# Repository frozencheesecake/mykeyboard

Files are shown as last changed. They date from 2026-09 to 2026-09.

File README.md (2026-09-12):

## **A mechanical keyboard.**

I  decided to embark on a mission to make my own mechanical keyboard from scratch. This includes designing the PCB and the case for the keyboard myeslf. Since I have not made any PCB's before, this was be a completely new experience and fruitful experience for me :)

##### Details

> 83 keys (~75% keyboard)

> Non-hotswappable Akko V3 Creamy Purple Pro Switches

> Runs on a Raspberry Pi Pico due to its powerful chip and the number of IO pins (26 pins)

> Has a 16x6 matrix

> 1N4148 through-hole diodes to prevent ghosting (The matrix is a useful way of succinctly employing a limited number of IO pins for a large number of keys.)

[Bill of Materials](https://github.com/bamb-boo/keyboard/blob/main/cart/bom-keyboard_kicad.csv)-
| Component name | Details | Qty | Bought from | Cost (usd) |
|---|---|---|---|---|
| Case | PLA | 1 | JLCPCB | ~70 |
| Plate | Resin | 1 | JLCPCB | 6 |
| Switches | Click Inc HP Switch (Pack of 10) | 9 packs | https://stackskb.com/store/click-inc-hp-switch-pack-of-10-pre-order/ | 17 |
| Keycaps | Color PBT | 83 keycaps | https://meckeys.com/shop/accessories/keyboard-accessories/keycaps/colour-pbt-keycaps/ | about 11 |
| M2 nuts and bolts | 15 mm height | 8 | Local vendor | 1 |
| Microcontroller | Raspberry Pi Pico | 1 | https://quartzcomponents.com/products/raspberry-pi-pico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 | 3.5 |
| Stabilizers | 4 x 2u + 1 x 6u | 5 | https://www.genesispc.in/products/durock-plate-mount-stabilizers-6-25u-4x2u-black?variant=43129560924213 | 4 |
| Diodes | 1n4148 | 83 | https://www.ktron.in/product/diode-1n4148-th/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 | 0.6 |

Exclaimer- the bom.csv in the cart dir is for all products. the bom.csv in the pcb dir is the bom generated by kicad itself. attaching both for convinience sake ig?

Future scope-

> A keyboard using a touchscreen to for more efficiency

> Wireless version using Pi Pico W.

There are two main folders, 1 for the PCB and another for the CAD files for the case and the plate. 

I had a faulty laptop keyboard, and wanted to get a mechanical keyboard. I felt creating my own mechanical keyboard will not only fix my need, but will also be a good learning opportunity.

Photos-





Build instructions-

Solder the diodes to the designated holes in the pcb, with the diodes pointing dows.

Solder the switches to the holes beside the diodes.

Attach the keycaps to the switches.

Attach the pcb to the plate, ensuring the fit snugly.

Bolt the plate to the case.

Viola, you're done!

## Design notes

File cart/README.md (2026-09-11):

all components-

pcb-


case and plate- friend

[switches](https://stackskb.com/store/click-inc-hp-switch-pack-of-10-pre-order/)

[keycaps](https://meckeys.com/shop/accessories/keyboard-accessories/keycaps/colour-pbt-keycaps/). alternative if not available- [https://meckeys.com/shop/accessories/keyboard-accessories/keycaps/royal-kludge-blue-mix-keycaps/](https://meckeys.com/shop/accessories/keyboard-accessories/keycaps/royal-kludge-blue-mix-keycaps/)

[stabilizers](https://www.genesispc.in/products/durock-plate-mount-stabilizers-6-25u-4x2u-black?variant=43129560924213)

microcontroller- raspberry pi pico

[1n4148 diodes](https://www.ktron.in/product/diode-1n4148-th/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)

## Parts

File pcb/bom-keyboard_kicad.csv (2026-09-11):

Id | Designator | Footprint | Quantity | Designation | Supplier and ref
1 | SW83,SW71,SW4,SW54,SW41,SW18,SW38,SW44,SW82,SW46,SW9,SW15,SW81,SW58,SW43,SW6,SW22,SW60,SW37,SW52,SW36,SW50,SW33,SW2,SW35,SW20,SW56,SW7,SW62,SW31,SW14,SW26,SW66,SW10,SW1,SW39,SW80,SW70,SW8,SW53,SW73,SW5,SW27,SW42,SW68,SW51,SW3,SW57,SW25,SW23,SW79,SW29,SW17,SW13,SW24,SW12,SW28,SW65,SW21,SW69,SW63,SW67,SW34,SW16,SW19,SW55,SW48,SW40,SW64,SW49,SW11 | MX_PCB_1.00u | 71 | SW_Push
2 | SW75,SW74,SW77,SW76 | MX_PCB_1.25u | 4 | SW_Push
3 | SW45,SW32 | MX_PCB_1.50u | 2 | SW_Push
4 | SW59,SW61 | MX_PCB_2.25u | 2 | SW_Push
5 | SW30 | MX_PCB_2.00u | 1 | SW_Push
6 | SW78 | Stabilizer_Cherry_MX_6.25u | 1 | SW_Push
7 | SW47 | MX_PCB_1.75u | 1 | SW_Push
8 | SW72 | MX_PCB_2.75u | 1 | SW_Push
9 | D52,D35,D94,D61,D90,D29,D97,D47,D23,D51,D63,D43,D26,D22,D38,D105,D67,D30,D17,D15,D19,D10,D69,D34,D82,D33,D39,D50,D66,D45,D77,D79,D59,D53,D64,D80,D104,D37,D73,D78,D36,D92,D65,D13,D88,D24,D20,D32,D11,D60,D44,D72,D42,D14,D12,D41,D95,D49,D16,D86,D93,D54,D27,D58,D18,D74,D31,D96,D85,D81,D28,D84,D75,D21,D56,D91,D55,D25,D57,D62,D48,D76,D46 | D_DO-35_SOD27_P3.81mm_Vertical_KathodeUp | 83 | ~
10 | U1 | Raspberry_Pi_Pico | 1 | Raspberry_Pi_Pico

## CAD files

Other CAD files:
cad/complete_build/case (Assembly).step
cad/case/keyboard_case.step
cad/plate/keyboard_case.stl
cad/plate/keyboard_plate.step
cad/case/case.f3d
cad/case/keyboard_case.stl
cad/complete_build/case (Assembly).f3z
cad/complete_build/case (Assembly).stl
cad/plate/plate.f3d

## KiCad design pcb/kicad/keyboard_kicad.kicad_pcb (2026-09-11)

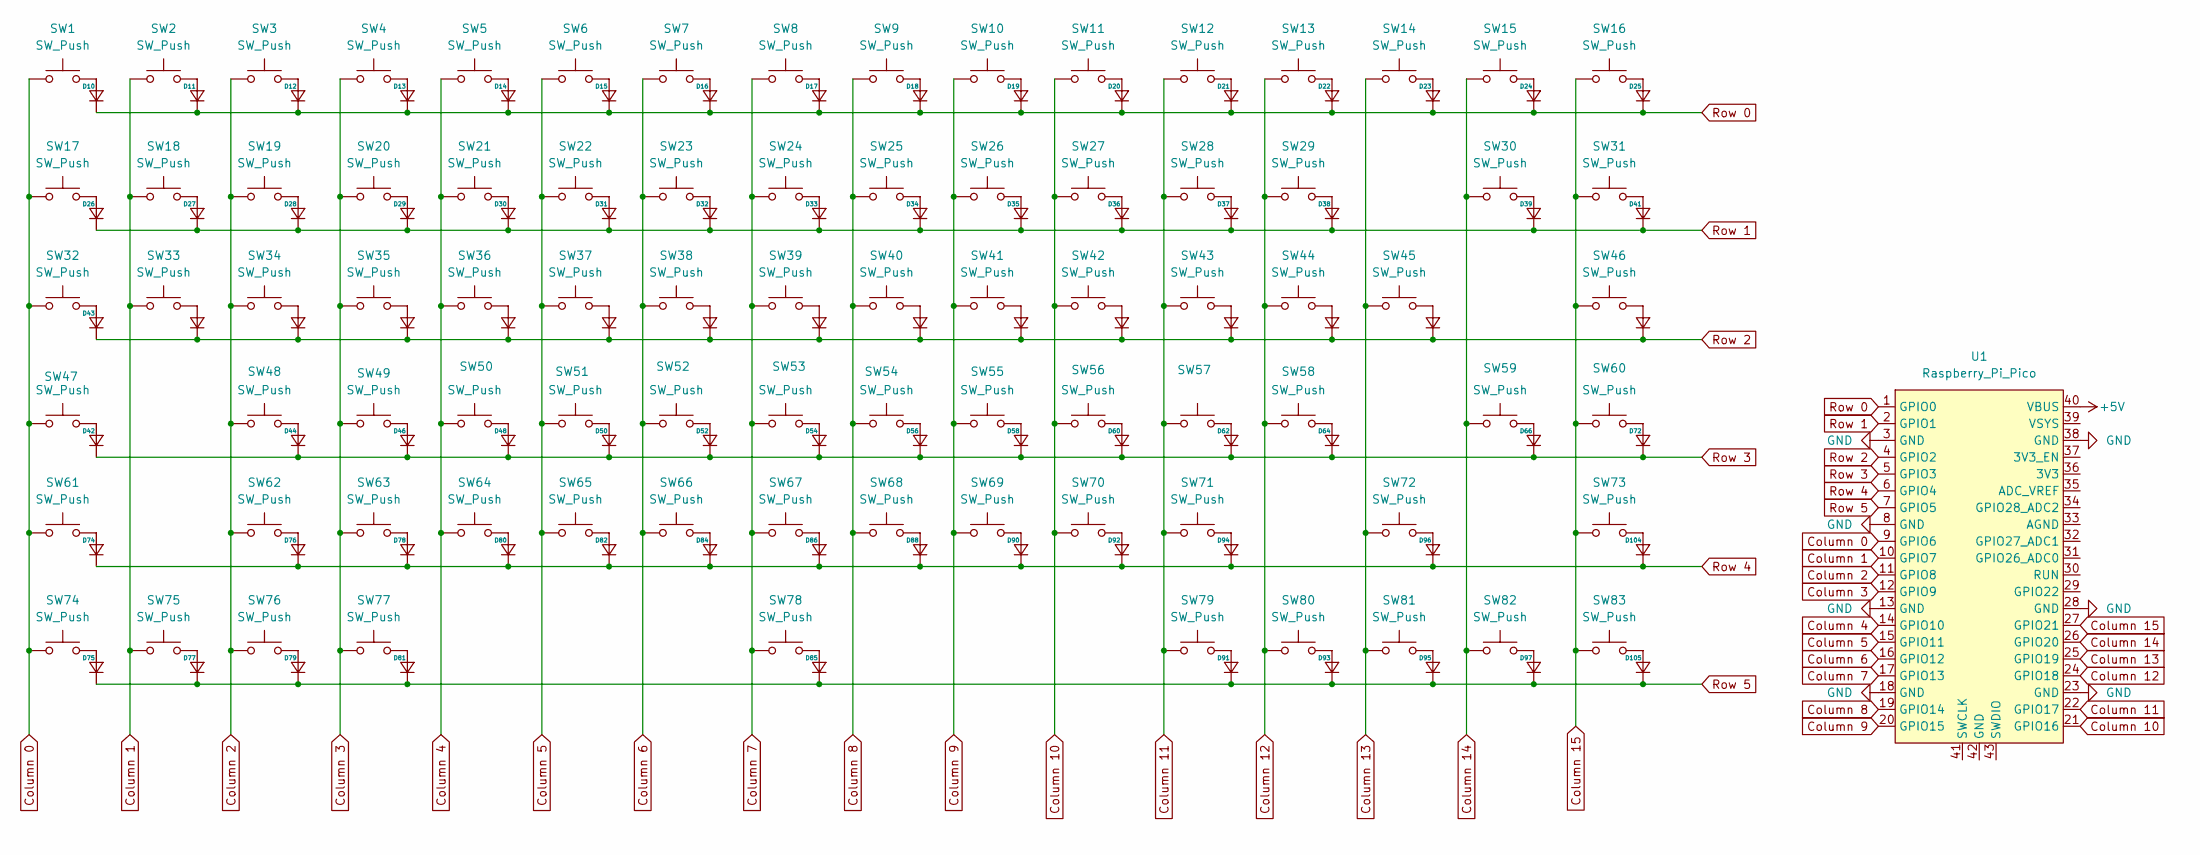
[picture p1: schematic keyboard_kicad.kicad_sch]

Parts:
D10, D11, D12, D13, D14, D15, D16, D17, D18, D19, D20, D21, D22, D23, D24, D25, D26, D27, D28, D29, D30, D31, D32, D33, D34, D35, D36, D37, D38, D39, D41, D42, D43, D44, D45, D46, D47, D48, D49, D50, D51, D52, D53, D54, D55, D56, D57, D58, D59, D60, D61, D62, D63, D64, D65, D66, D67, D69, D72, D73, D74, D75, D76, D77, D78, D79, D80, D81, D82, D84, D85, D86, D88, D90, D91, D92, D93, D94, D95, D96, D97, D104, D105: D_DO-35_SOD27_P3.81mm_Vertical_KathodeUp
SW1, SW2, SW3, SW4, SW5, SW6, SW7, SW8, SW9, SW10, SW11, SW12, SW13, SW14, SW15, SW16, SW17, SW18, SW19, SW20, SW21, SW22, SW23, SW24, SW25, SW26, SW27, SW28, SW29, SW31, SW33, SW34, SW35, SW36, SW37, SW38, SW39, SW40, SW41, SW42, SW43, SW44, SW46, SW48, SW49, SW50, SW51, SW52, SW53, SW54, SW55, SW56, SW57, SW58, SW60, SW62, SW63, SW64, SW65, SW66, SW67, SW68, SW69, SW70, SW71, SW73, SW79, SW80, SW81, SW82, SW83: SW_Push; MX_PCB_1.00u
SW30: SW_Push; MX_PCB_2.00u
SW32, SW45: SW_Push; MX_PCB_1.50u
SW47: SW_Push; MX_PCB_1.75u
SW59, SW61: SW_Push; MX_PCB_2.25u
SW72: SW_Push; MX_PCB_2.75u
SW74, SW75, SW76, SW77: SW_Push; MX_PCB_1.25u
SW78: SW_Push; Stabilizer_Cherry_MX_6.25u
U1: Raspberry_Pi_Pico

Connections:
+5V: U1.40 (VBUS)
Column 0: SW1.1, SW17.1, SW32.1, SW47.1, SW61.1, SW74.1, U1.9 (GPIO6)
Column 1: SW2.1, SW18.1, SW33.1, SW75.1, U1.10 (GPIO7)
Column 2: SW3.1, SW19.1, SW34.1, SW48.1, SW62.1, SW76.1, U1.11 (GPIO8)
Column 3: SW4.1, SW20.1, SW35.1, SW49.1, SW63.1, SW77.1, U1.12 (GPIO9)
Column 4: SW5.1, SW21.1, SW36.1, SW50.1, SW64.1, U1.14 (GPIO10)
Column 5: SW6.1, SW22.1, SW37.1, SW51.1, SW65.1, U1.15 (GPIO11)
Column 6: SW7.1, SW23.1, SW38.1, SW52.1, SW66.1, U1.16 (GPIO12)
Column 7: SW8.1, SW24.1, SW39.1, SW53.1, SW67.1, SW78.1, U1.17 (GPIO13)
Column 8: SW9.1, SW25.1, SW40.1, SW54.1, SW68.1, U1.19 (GPIO14)
Column 9: SW10.1, SW26.1, SW41.1, SW55.1, SW69.1, U1.20 (GPIO15)
Column 10: SW11.1, SW27.1, SW42.1, SW56.1, SW70.1, U1.21 (GPIO16)
Column 11: SW12.1, SW28.1, SW43.1, SW57.1, SW71.1, SW79.1, U1.22 (GPIO17)
Column 12: SW13.1, SW29.1, SW44.1, SW58.1, SW80.1, U1.24 (GPIO18)
Column 13: SW14.1, SW45.1, SW72.1, SW81.1, U1.25 (GPIO19)
Column 14: SW15.1, SW30.1, SW59.1, SW82.1, U1.26 (GPIO20)
Column 15: SW16.1, SW31.1, SW46.1, SW60.1, SW73.1, SW83.1, U1.27 (GPIO21)
GND: U1.3 (GND), U1.8 (GND), U1.13 (GND), U1.18 (GND), U1.23 (GND), U1.28 (GND), U1.38 (GND)
unnamed: D10.2 (A), SW1.2
unnamed: D11.2 (A), SW2.2
unnamed: D12.2 (A), SW3.2
unnamed: D13.2 (A), SW4.2
unnamed: D14.2 (A), SW5.2
unnamed: D15.2 (A), SW6.2
unnamed: D16.2 (A), SW7.2
unnamed: D17.2 (A), SW8.2
unnamed: D18.2 (A), SW9.2
unnamed: D19.2 (A), SW10.2
unnamed: D20.2 (A), SW11.2
unnamed: D21.2 (A), SW12.2
unnamed: D22.2 (A), SW13.2
unnamed: D23.2 (A), SW14.2
unnamed: D24.2 (A), SW15.2
unnamed: D25.2 (A), SW16.2
unnamed: D26.2 (A), SW17.2
unnamed: D27.2 (A), SW18.2
unnamed: D28.2 (A), SW19.2
unnamed: D29.2 (A), SW20.2
unnamed: D30.2 (A), SW21.2
unnamed: D31.2 (A), SW22.2
unnamed: D32.2 (A), SW23.2
unnamed: D33.2 (A), SW24.2
unnamed: D34.2 (A), SW25.2
unnamed: D35.2 (A), SW26.2
unnamed: D36.2 (A), SW27.2
unnamed: D37.2 (A), SW28.2
unnamed: D38.2 (A), SW29.2
unnamed: D39.2 (A), SW30.2
unnamed: D41.2 (A), SW31.2
unnamed: D42.2 (A), SW47.2
unnamed: D43.2 (A), SW32.2
unnamed: D44.2 (A), SW48.2
unnamed: D45.2 (A), SW33.2
unnamed: D46.2 (A), SW49.2
unnamed: D47.2 (A), SW34.2
unnamed: D48.2 (A), SW50.2
unnamed: D49.2 (A), SW35.2
unnamed: D50.2 (A), SW51.2
unnamed: D51.2 (A), SW36.2
unnamed: D52.2 (A), SW52.2
unnamed: D53.2 (A), SW37.2
unnamed: D54.2 (A), SW53.2
unnamed: D55.2 (A), SW38.2
unnamed: D56.2 (A), SW54.2
unnamed: D57.2 (A), SW39.2
unnamed: D58.2 (A), SW55.2
unnamed: D59.2 (A), SW40.2
unnamed: D60.2 (A), SW56.2
unnamed: D61.2 (A), SW41.2
unnamed: D62.2 (A), SW57.2
unnamed: D63.2 (A), SW42.2
unnamed: D64.2 (A), SW58.2
unnamed: D65.2 (A), SW43.2
unnamed: D66.2 (A), SW59.2
unnamed: D67.2 (A), SW44.2
unnamed: D69.2 (A), SW45.2
unnamed: D72.2 (A), SW60.2
unnamed: D73.2 (A), SW46.2
unnamed: D74.2 (A), SW61.2
unnamed: D75.2 (A), SW74.2
unnamed: D76.2 (A), SW62.2
unnamed: D77.2 (A), SW75.2
unnamed: D78.2 (A), SW63.2
unnamed: D79.2 (A), SW76.2
unnamed: D80.2 (A), SW64.2
unnamed: D81.2 (A), SW77.2
unnamed: D82.2 (A), SW65.2
unnamed: D84.2 (A), SW66.2
unnamed: D85.2 (A), SW78.2
unnamed: D86.2 (A), SW67.2
unnamed: D88.2 (A), SW68.2
unnamed: D90.2 (A), SW69.2
unnamed: D91.2 (A), SW79.2
unnamed: D92.2 (A), SW70.2
unnamed: D93.2 (A), SW80.2
unnamed: D94.2 (A), SW71.2
unnamed: D95.2 (A), SW81.2
unnamed: D96.2 (A), SW72.2
unnamed: D97.2 (A), SW82.2
unnamed: D104.2 (A), SW73.2
unnamed: D105.2 (A), SW83.2
Row 0: D10.1 (K), D11.1 (K), D12.1 (K), D13.1 (K), D14.1 (K), D15.1 (K), D16.1 (K), D17.1 (K), D18.1 (K), D19.1 (K), D20.1 (K), D21.1 (K), D22.1 (K), D23.1 (K), D24.1 (K), D25.1 (K), U1.1 (GPIO0)
Row 1: D26.1 (K), D27.1 (K), D28.1 (K), D29.1 (K), D30.1 (K), D31.1 (K), D32.1 (K), D33.1 (K), D34.1 (K), D35.1 (K), D36.1 (K), D37.1 (K), D38.1 (K), D39.1 (K), D41.1 (K), U1.2 (GPIO1)
Row 2: D43.1 (K), D45.1 (K), D47.1 (K), D49.1 (K), D51.1 (K), D53.1 (K), D55.1 (K), D57.1 (K), D59.1 (K), D61.1 (K), D63.1 (K), D65.1 (K), D67.1 (K), D69.1 (K), D73.1 (K), U1.4 (GPIO2)
Row 3: D42.1 (K), D44.1 (K), D46.1 (K), D48.1 (K), D50.1 (K), D52.1 (K), D54.1 (K), D56.1 (K), D58.1 (K), D60.1 (K), D62.1 (K), D64.1 (K), D66.1 (K), D72.1 (K), U1.5 (GPIO3)
Row 4: D74.1 (K), D76.1 (K), D78.1 (K), D80.1 (K), D82.1 (K), D84.1 (K), D86.1 (K), D88.1 (K), D90.1 (K), D92.1 (K), D94.1 (K), D96.1 (K), D104.1 (K), U1.6 (GPIO4)
Row 5: D75.1 (K), D77.1 (K), D79.1 (K), D81.1 (K), D85.1 (K), D91.1 (K), D93.1 (K), D95.1 (K), D97.1 (K), D105.1 (K), U1.7 (GPIO5)

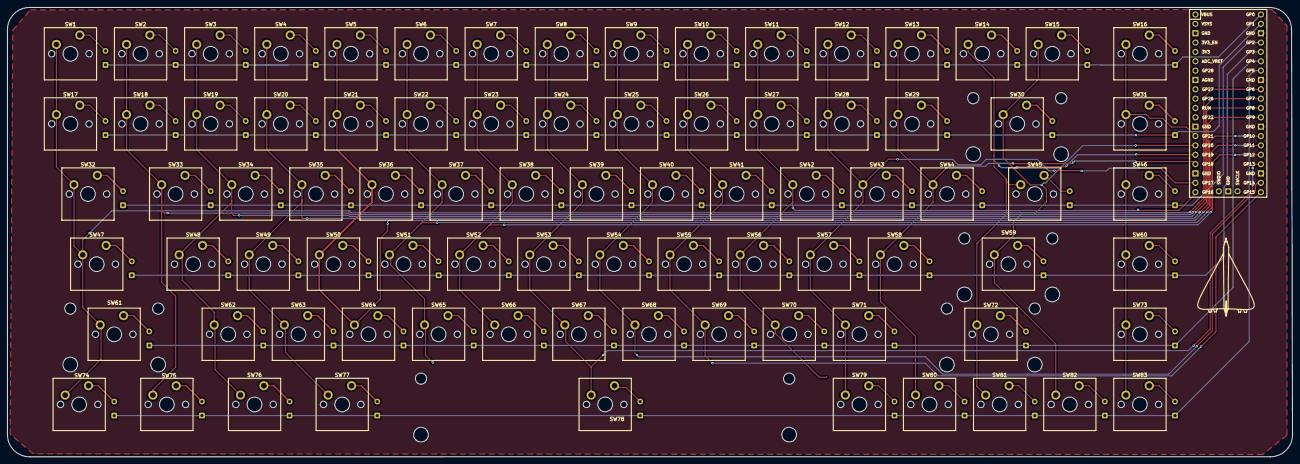
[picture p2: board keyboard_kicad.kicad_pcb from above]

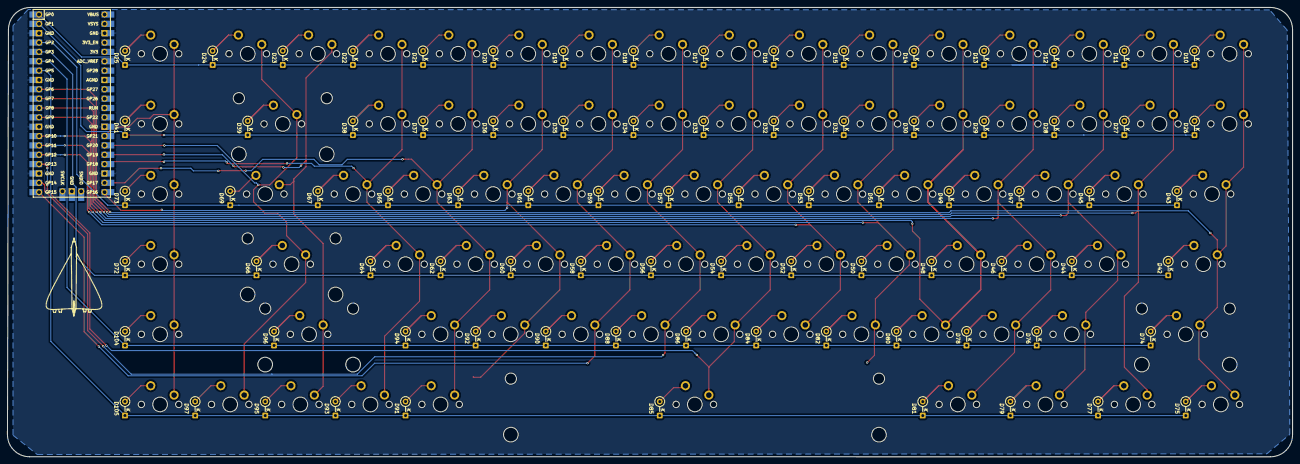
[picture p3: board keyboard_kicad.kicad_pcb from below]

Board: 2 copper layers, 349.1 x 122.0 mm, 167 parts (84 on the bottom side), 106 nets.
